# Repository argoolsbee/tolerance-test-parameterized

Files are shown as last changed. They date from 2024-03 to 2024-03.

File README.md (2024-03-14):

# Tolerance Test - Parametric

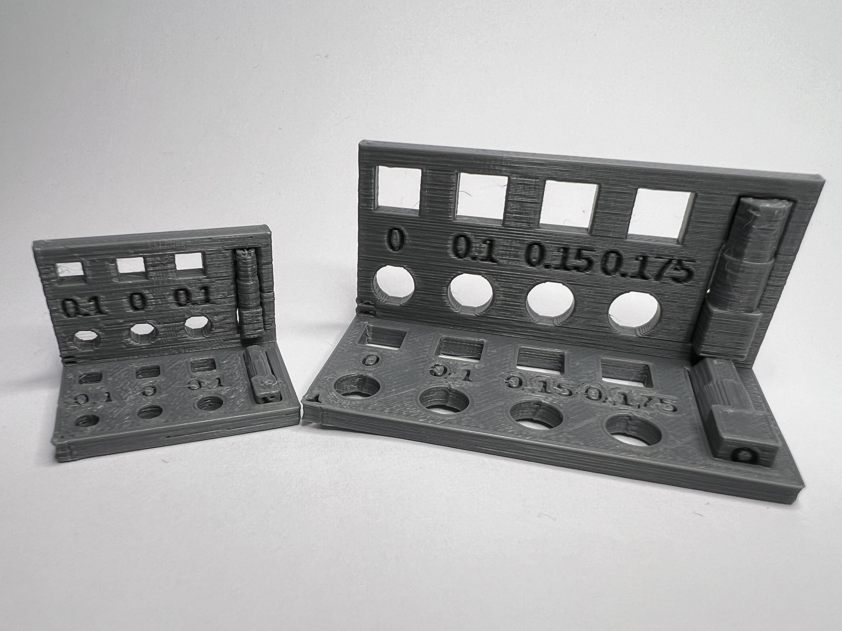
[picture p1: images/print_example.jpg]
3D printed example
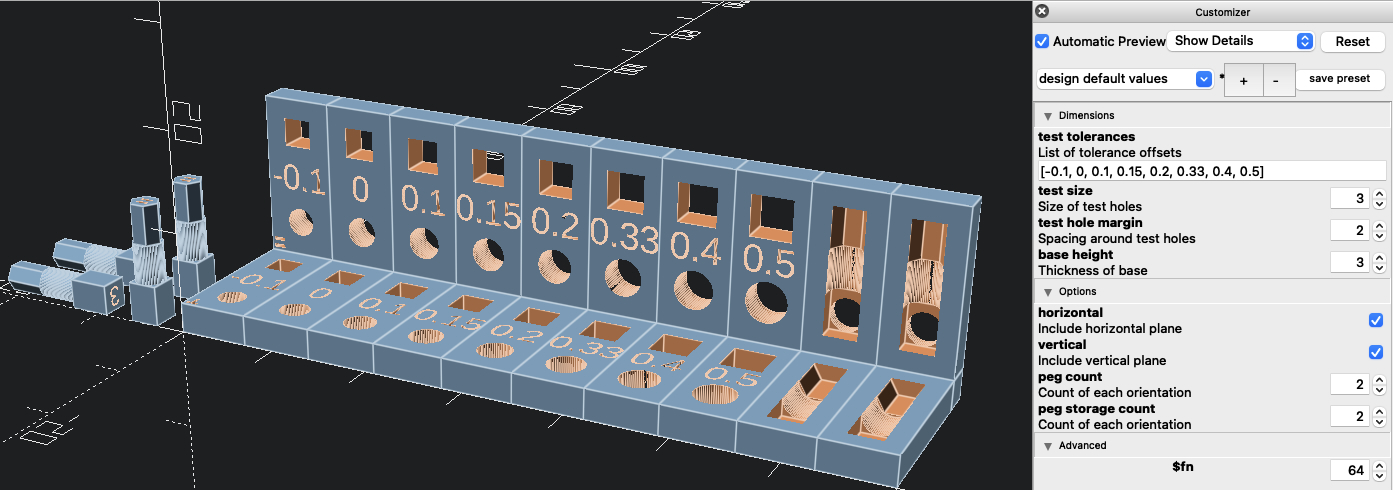
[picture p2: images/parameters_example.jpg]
Parameters Example
 

Hosted on [Printables](https://www.printables.com/model/779616-tolerance-test-parametric). Recreated [Tolerance Test by jczuba](https://www.printables.com/model/740643-tolerance-test) in OpenSCAD.

Desired tolerances/clearances differ depending on the print orientation of the pieces you are fitting together. This model lets you test for a variety of combinations of holes/pegs printed with axes parallel and perpendicular to the print bed.

The body of the tester has circular and square variable size holes printed with the center axis perpendicular and parallel to the print bed with customizable tolerances. 

The pegs have square section, circular section (middle), and octagonal section printed perpendicular and parallel to the print bed. Both the circular and octagonal sections are meant to be tested in the circular opening. Depending on the necessary print orientation, printing an octagonal section rather than a circular section might be a better option. This lets you test both options.

The base size of the tester is inscribed on the bottom/back of the body and pegs. The body of the tester and the pegs are inscribed with the orientation those axes were printed at to help remember their printing orientation. The body of the tester also includes slots to store the pegs between uses.

### Printing instructions
1. Create your own model with desired size and offsets using tolerance_test.scad.
1. Print in whatever settings and filament you are planning for your main print that you want to test tolerances.

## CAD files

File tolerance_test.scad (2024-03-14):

// Tolerance/Clearance Tester
// Design inspired by jczuba (https://www.printables.com/model/740643-tolerance-test)
// Parameterized version by argoolsbee (https://www.printables.com/model/779616-tolerance-test-parameterized)

/* [Dimensions] */
// List of tolerance offsets
test_tolerances = [-0.1, 0, 0.1, 0.15, 0.2, 0.33, 0.4, 0.5];
// Size of test holes
test_size = 3;
// Spacing around test holes
test_hole_margin = 2;
// Thickness of base
base_height = 3.0;

/* [Options] */
// Include horizontal plane
horizontal = true;
// Include vertical plane
vertical = true;
// Count of each orientation 
peg_count = 1;
// Count of each orientation 
peg_storage_count = 1;

/* [Advanced] */
$fn = 64;

/* [Hidden] */
eps = 0.01;
PERPENDICULAR = "PERPENDICULAR";
PARALLEL = "PARALLEL";

test_count = len(test_tolerances);
base_unit_width = test_size + (test_hole_margin * 2);
base_depth = (test_hole_margin * 5) + (test_size * 2);

module parallel_symbol() {
    square([test_size / 2.5, test_size / 8]);
    
    translate([0, test_size / 4, 0])
        square([test_size / 2.5, test_size / 8]);
}

module perpendicular_symbol() {
    square([test_size / 2.5, test_size / 8]);
    
    translate([test_size / 3.75, 0, 0])
        rotate([0, 0, 90])
            square([test_size / 2.5, test_size / 8]);
}

module base(test_tolerances, test_size, test_hole_margin, base_height, orientation) {
    difference() {
        for(i = [0 : 1 : test_count - 1]) {
            test_tolerance = test_tolerances[i];
            test_hole = test_size + (test_tolerance * 2);
            
            translate([base_unit_width * i, 0, 0]) {
                difference() {
                    cube([base_unit_width, base_depth, base_height]);
                    // square
                    translate([test_hole_margin - test_tolerance, base_depth - test_hole_margin - test_hole, 0 - eps])
                        cube([test_hole, test_hole, base_height + (2 * eps)]);
                    // text
                    translate([base_unit_width / 2, base_depth / 2,  3 - 1 + eps])
                        linear_extrude(1)
                            text(str(test_tolerance), size = test_hole_margin * 1.33333, halign = "center", valign = "center");
                    // circle 
                    translate([test_hole_margin + (test_hole / 2) - test_tolerance, test_hole_margin + (test_hole / 2), 0 - eps])
                        cylinder(h = base_height + (2 * eps), d = test_hole);
                }
            }
        }
        
        // orientation symbols
        if(orientation == PARALLEL) {
            translate([0.3, 0.3, -eps])
                linear_extrude(base_height + (eps * 2))
                    parallel_symbol();
        } else if(orientation == PERPENDICULAR) {
            translate([0.3, 0.3, -eps])
                linear_extrude(base_height + (eps * 2))
                    perpendicular_symbol();
        }
        
        // test size text 
        translate([base_unit_width / 2, base_depth / 2, 1 - eps])
            rotate([0, 180, 0])
                linear_extrude(1)
                    text(str(test_size), size = test_hole_margin * 1.33333, halign = "center", valign = "center");
    }
    
    // peg storage
    peg_storage_offset = 0.2;
    for(i = [1 : 1 : peg_storage_count]) {
        translate([base_unit_width * (test_count + i - 1), 0, 0])
            difference() {
                cube([base_unit_width, base_depth, base_height]);
                
                translate([test_hole_margin - (peg_storage_offset / 2), test_hole_margin - (peg_storage_offset / 2), base_height + (test_size / 2)])
                    rotate([-90, 0, 0])
                        peg(offset = peg_storage_offset);
                
                translate([test_hole_margin + (test_size / 2), test_hole_margin + (test_size / 2), 0 - eps])
                    cylinder(h = base_height + eps, d = test_size + (peg_storage_offset));
            }
    }

}

module peg(offset = 0, orientation) {
    peg_width = test_size + offset;
    peg_depth = test_size + offset;
    peg_length = (test_size * 2) + (test_hole_margin * 3) + offset;
    segment_length = peg_length / 3;
    
    difference() {
        union() {
            // square
            cube([peg_width, peg_depth, segment_length]);
            // circle
            translate([peg_width / 2, peg_depth / 2, segment_length - eps])
                cylinder(d = peg_width, h = segment_length + eps);
            // hexigon
            translate([peg_width / 2, peg_depth / 2, (segment_length * 2) - eps])
                cylinder(d = peg_width, h = segment_length + eps, $fn=6);
            
            
        }
        
        // test size text
        if(orientation) {
            translate([(test_size / 2), (test_size / 2), 1 - eps])
                    rotate([0, 180, 0])
                        linear_extrude(1)
                            text(str(test_size), size = test_size * .66, halign = "center", valign = "center");
        }
        
        // orientation symbols
        if(orientation == PARALLEL) {
            translate([(test_size / 3.3333), (test_size / 3.25), peg_length - 0.6])
                linear_extrude(0.6 + eps)
                    parallel_symbol();
        } else if(orientation == PERPENDICULAR) {          
            translate([(test_size / 3.3333), (test_size / 3.25), peg_length - 0.6])
                linear_extrude(0.6 + eps)
                    perpendicular_symbol();
        }
    }
}

// base
difference() {
    union() {
        if(horizontal) {
            base(test_tolerances, test_size, test_hole_margin, base_height, PERPENDICULAR);
        }
        
        if(vertical && !horizontal) {
            translate([0, base_height, 0])
                rotate([90, 0, 0])
                    base(test_tolerances, test_size, test_hole_margin, base_height, PARALLEL);
        }
    
        if(horizontal && vertical) {
            translate([0, base_depth + base_height, base_height])
                rotate([90, 0, 0])
                    base(test_tolerances, test_size, test_hole_margin, base_height, PARALLEL);
        
            translate([0, base_depth, 0])
                cube([(base_unit_width * test_count) + (base_unit_width * peg_storage_count), base_height, base_height]);
        }
    }
}

// pegs
for(i = [0 : 1 : peg_count - 1]) {
    translate([-test_size - test_size, i * (test_size + (test_hole_margin * 2)), 0])
        peg(orientation = PARALLEL);
    
    translate([-(test_size * 3), i * (test_size + (test_hole_margin * 2)), test_size])
        rotate([-90, 0, 90])
            peg(orientation = PERPENDICULAR);
}

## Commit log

2024-02-24 Add Tolerance_test.scad
    [Tolerance_test.scad]
2024-03-14 Update and rename Tolerance_test.scad to tolerance_test.scad
    [tolerance_test.scad]
